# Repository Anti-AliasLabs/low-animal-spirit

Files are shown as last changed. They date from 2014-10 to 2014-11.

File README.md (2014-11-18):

Low Animal Spirit
=================

Scrolling LED matrix sign displaying Twitter feed from an Arduino Yun.

Setting up the Yun (upgraded to 1.5.1)
--------------------------------------
* Setup network connection (whether ethernet or wifi)
* SSH into Yun
* Update opkg, install easy_install, and ssl for Python

`> opkg update`

`> opkg install distribute`

`> opkg install python-openssl`

* Install twython and simplejson

`> easy_install twython`

`> easy_install simplejson`

* scp tweet-controller.py and credentials.py onto Yun
* Put token information in credentials.py

To start Python Twitter script
------------------------
* ssh to the Linino side of the Yun

`> ssh root@arduino.local`

* the password is arduino
* once logged in start the script

`> python tweet-controller.py &`

* once a new tweet is read, it should be printed to the screen along with the length of the tweet in characters (this is the data passed to the microcontroller side of the Yun)

Microcontroller
---------------
Uses Adafruit's HT1632 and GFX libraries. The HT1632 library uses the code in pull request https://github.com/adafruit/HT1632/pull/2/files

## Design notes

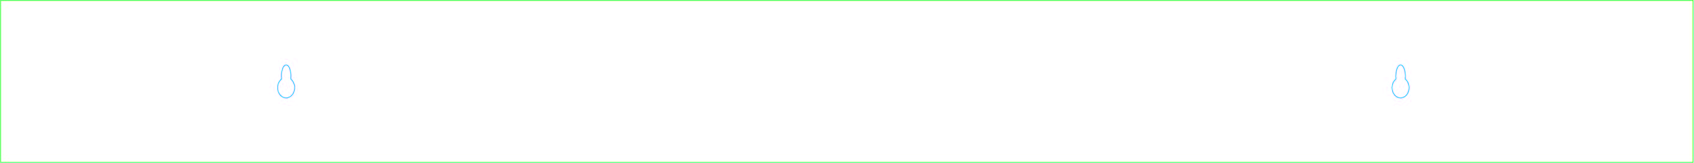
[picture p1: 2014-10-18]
physical_sign/sign-laser-cutter.jpg

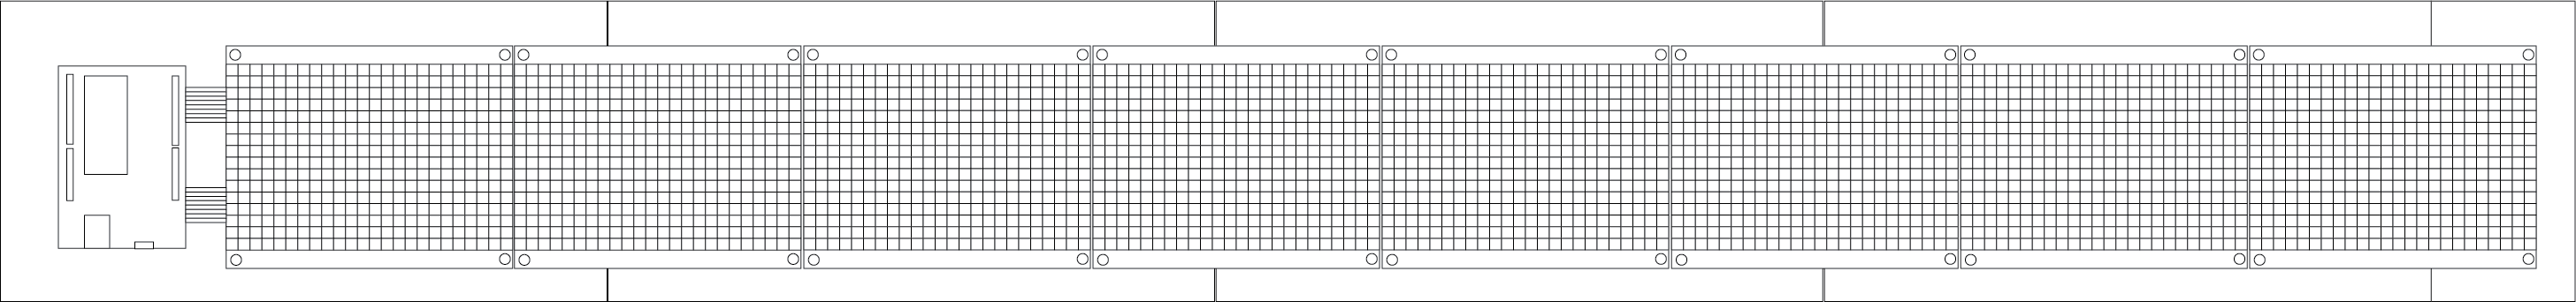
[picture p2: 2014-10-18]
physical_sign/sign-sketch.png

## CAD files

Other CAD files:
physical_sign/sign-laser-cutter.dwg

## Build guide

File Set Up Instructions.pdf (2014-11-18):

# Low Animal Spirit LED Sign

## To Start Sign

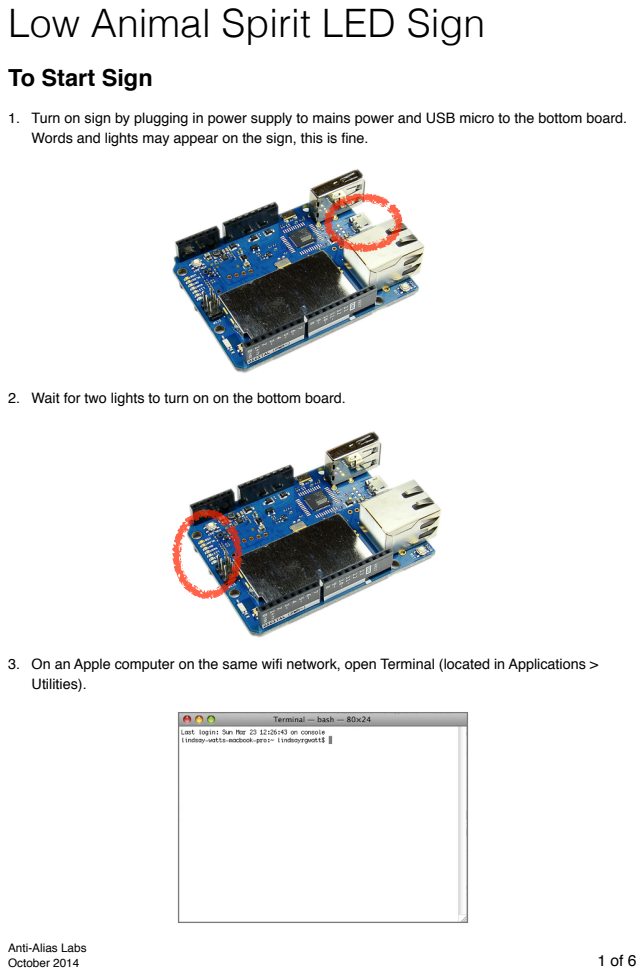
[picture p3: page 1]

1. Turn on sign by plugging in power supply to mains power and USB micro to the bottom board.
Words and lights may appear on the sign, this is fine.

2. Wait for two lights to turn on on the bottom board.

3. On an Apple computer on the same wifi network, open Terminal (located in Applications >
Utilities).

Anti-Alias Labs
October 2014

4. Type:
ssh root@arduino.local
then hit enter.
5. If the Terminal prints a message about not resolving the name, wait a minute and then try again. If it still doesn’t work after 10 minutes, you may need to set up the sign’s wifi again. If a yes/no question appears, type yes then hit enter.
6. When asked for a password type
arduino
then hit enter.
The letters you type for the password won’t appear on the screen!
7. A welcome screen will appear.

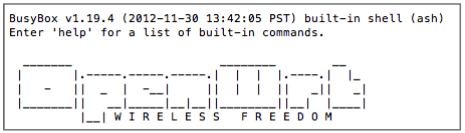
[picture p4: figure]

8. Press the white button on the board for 1 second and then release.
9. In the terminal type

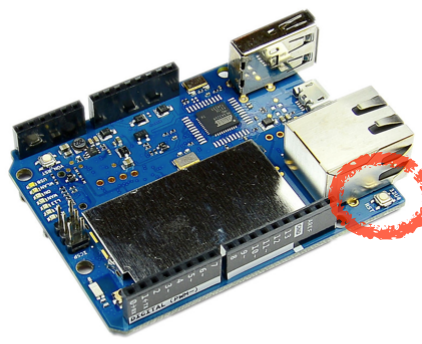
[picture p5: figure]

python tweet-controller.py &
then hit enter.
10. Wait and watch for tweets to be printed on the screen. This may take up to 5 minutes. You can also go to http://twitter.com/lowanimalspirit to make sure headlines are being tweeted. Within 5 minutes or so of tweets appearing on the screen, tweets should appear on the sign.
11. When you are done, type
exit
then hit enter. This won’t stop the sign from working. It will just disconnect your computer from talking with the sign.
12. Quite Terminal.

## To Stop Sign

1. Simply unplug the power supply.

## To Set Up Joining a New Wifi Network

## Only needs to be done once

1. Turn on sign by plugging in power supply to mains power and USB micro to the bottom board. Words and lights may appear on the sign, this is fine.
2. Wait for two lights to turn on on the bottom board.

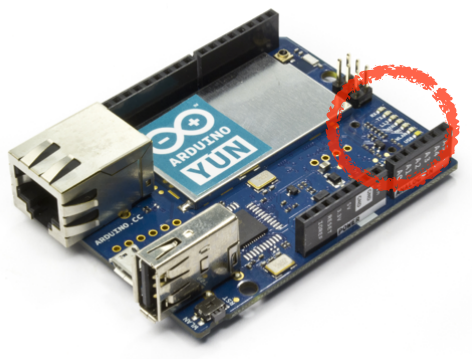
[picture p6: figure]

3. Press and hold the small black button labelled WLAN for 5 seconds then release.

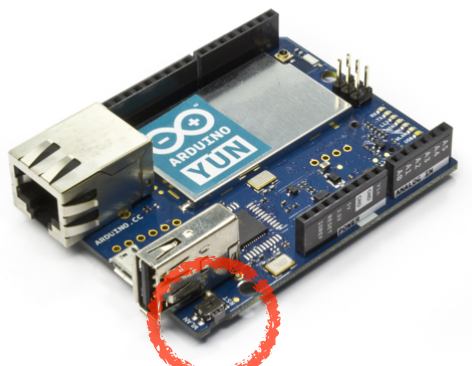
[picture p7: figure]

4. Wait 30 seconds.
5. Unplug the sign, turning it off. Then immediately power it again turning it on.
6. Wait for two lights to light up on the bottom board.
7. With a computer, look for a wifi network called “Arduino-Yun” and join it.

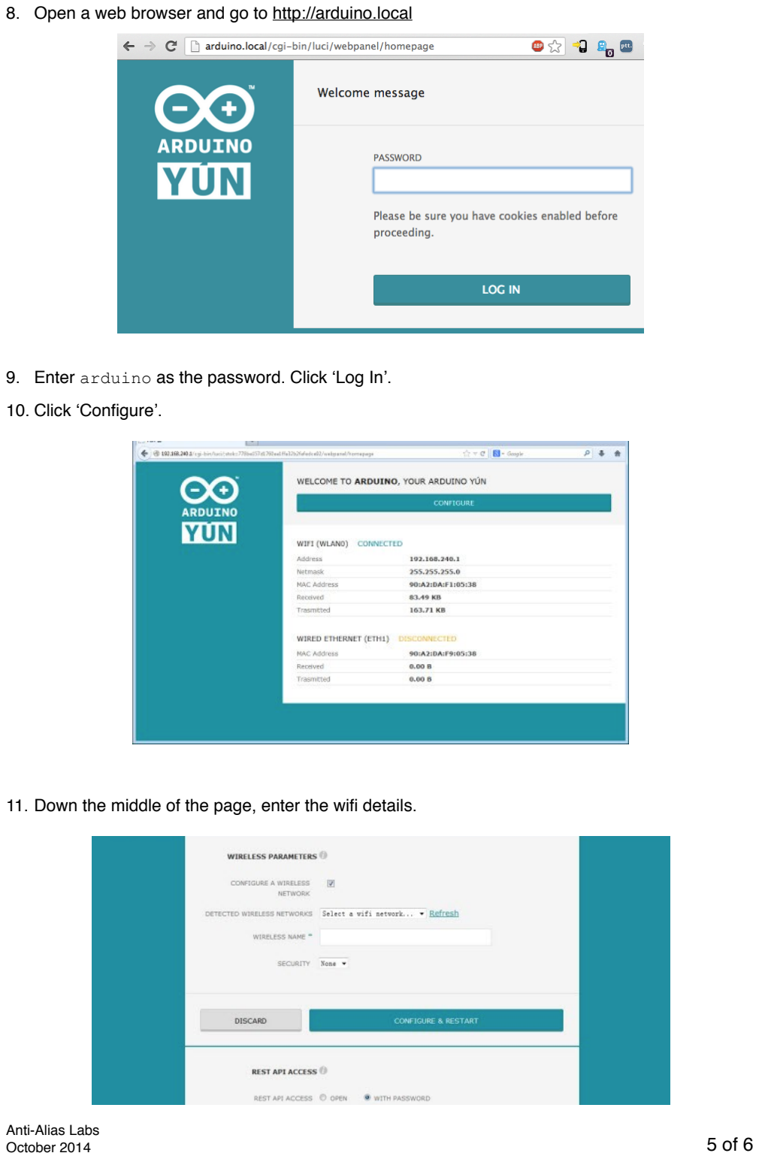
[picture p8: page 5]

8. Open a web browser and go to http://arduino.local
9. Enter arduino as the password. Click ‘Log In’.
10. Click ‘Configure’.
11. Down the middle of the page, enter the wifi details.

12. Click ‘Configure & Restart’.
13. Join the main wifi network.
14. Once the progress bar is completed, the sign is ready to be started.

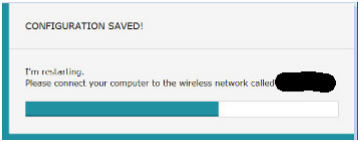
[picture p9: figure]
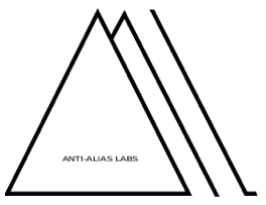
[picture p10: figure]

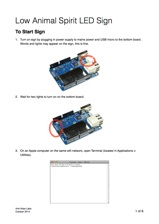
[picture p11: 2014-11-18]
Set Up Instructions.pages/preview-web.jpg

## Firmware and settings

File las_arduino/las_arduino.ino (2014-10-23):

#include "HT1632.h"
#include <Bridge.h>

#define DATA 2
#define WR   3
#define CS0  4
#define CS1  5
#define CS2  6
#define CS3  7
#define CS4  8
#define CS5  9
#define CS6  10
#define CS7  11

HT1632LEDMatrix matrix = HT1632LEDMatrix(DATA, WR, CS0, CS1, CS2, CS3, CS4, CS5, CS6, CS7);

int numDisplays = 8;
int textX = 0;
int stringIndex = 0;
int lenTweet = 26;

char tweetValue[4];    // incoming storage of tweet
int lastTweetCount = 0; // keep track of number of tweets
char tweetText[141];
char bridgeTweet[141];
int currChar = 1;

int currTextChar = 0;

boolean debugMode = false;
String t = "";
String startString = " Waiting............... *** ";


boolean displayHandle = false;
int tweetCounter = 0;

//-------------------------------------------
void setup() {

  if (debugMode) {
    Serial.begin(9600);
    while (!Serial) {

    }
    Serial.println("Beginning bridge");
  }
  Bridge.begin();    // initialise Bridge
  matrix.begin(HT1632_COMMON_16NMOS);

  // set up for text display
  matrix.setTextSize(1.5);    // size 1 == 8 pixels high
  matrix.setTextColor(1);   // 'lit' LEDs

  // start with string for waiting

  startString.toCharArray(tweetText, 141);

  for (int i = 0; i < 35; i++ ) {
    t += nextChar();
  }
}

//-------------------------------------------
void loop() {
  // scroll width of one character
  for (int tX = 0; tX > -6; tX--) {
    matrix.fillRect(0, 0, 24 * numDisplays, 16, 0);
    matrix.setCursor(tX, 4);

    matrix.print(t);
    matrix.writeScreen();
    delay(1);
  }
  if (debugMode) {
    Serial.println(t);
  }
  // progress through char array
  t = t.substring(1);
  t += nextChar();
}

//-------------------------------------------
char nextChar() {
  currChar++;

  // if completed buffer and not displaying handle
  if (currChar > lenTweet && !displayHandle) {
    currChar = 0;
    tweetCounter++;
    // if number of tweets have gone by
    if ( tweetCounter > 1 ) {
      lenTweet = 21;
      String handle = " @LowAnimalSpirit *** ";
      handle.toCharArray( tweetText, 141 );

      tweetCounter = 0;
      displayHandle = true;
      if ( debugMode) {
        Serial.println("---------display handle---------");
      }
    }
  }
  // if completed buffer and displaying handle
  if (currChar > lenTweet && displayHandle) {
    currChar = 0;
    tweetCounter++;
    // if number of tweets have gone by
    if ( tweetCounter > 0 ) {
      // clear text in buffer
      for (int i = 0; i < 141; i++) {
        tweetText[i] = ' ';
      }
      if ( debugMode) {
        Serial.println("---------reading in next tweet---------");
      }
      // read in waiting tweet
      Bridge.get("text", tweetText, 141);
      Bridge.get("tweetlength", tweetValue, 3);
      lenTweet = atoi(tweetValue)-1;
      //lenTweet = 30;
      Serial.println(tweetText);
      Serial.println(tweetValue);
      if ( atoi(tweetValue) < 2 ) {
        if ( debugMode) {
          Serial.println("---------keep waiting---------");
        }
        startString.toCharArray(tweetText, 141);
        lenTweet = 26;
      }
      tweetCounter = 0;
      displayHandle = false;
    }
  }
  return tweetText[currChar];
}

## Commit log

2014-10-18 Starting example code for controlling LED displays
2014-10-18 Adding images for physical sign creation
    [sign-laser-cutter.dwg]
2014-10-21 Arduino talking to all 8 displays
2014-10-23 Display tweets on LEDs, just doesn't auto-launch
    [las_arduino.ino]
